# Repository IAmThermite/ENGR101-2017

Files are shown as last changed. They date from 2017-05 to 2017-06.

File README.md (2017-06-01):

# Team *High Ground* AVC


## Team Members
* Tom - Head of Software - tom.buurmans@gmail.com
* Isaac - Hardware - isaachamiltonj@gmail.com
* Xavier - Software - Xavier.Broadhead@gmail.com
* Raven - Head of Hardware - Ravengotztier@icloud.com
* Luke - Admin - luke.honiss@gmail.com

## Information
* [Google Docs Link](https://docs.google.com/document/d/1r9uR-22ZHVupD0Ts2tCpkkdqB7kD9Vjael_ExiJzlJU/edit?usp=sharing)
    * This will be a general place for team members to put code snippets or paste pictures of progress and more general items that don't belong directly on this document.
* We are using a Facebook Group chat to communicate
<table>
   <th colspan="3">First robot design</th>
   <tr>
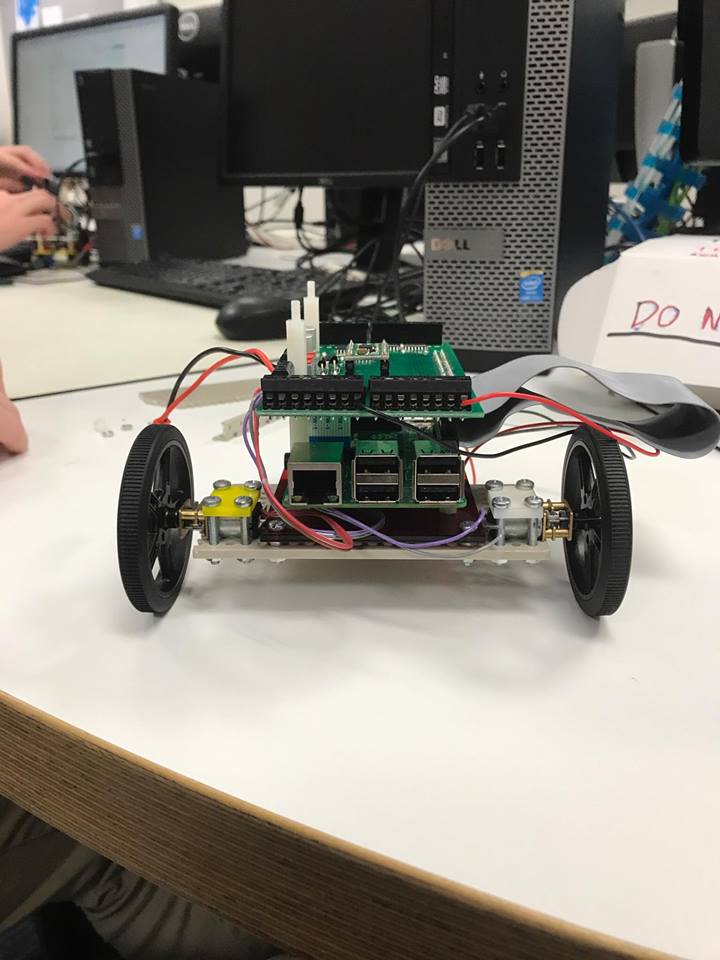
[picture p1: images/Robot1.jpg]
Robot 1
      <td></td>
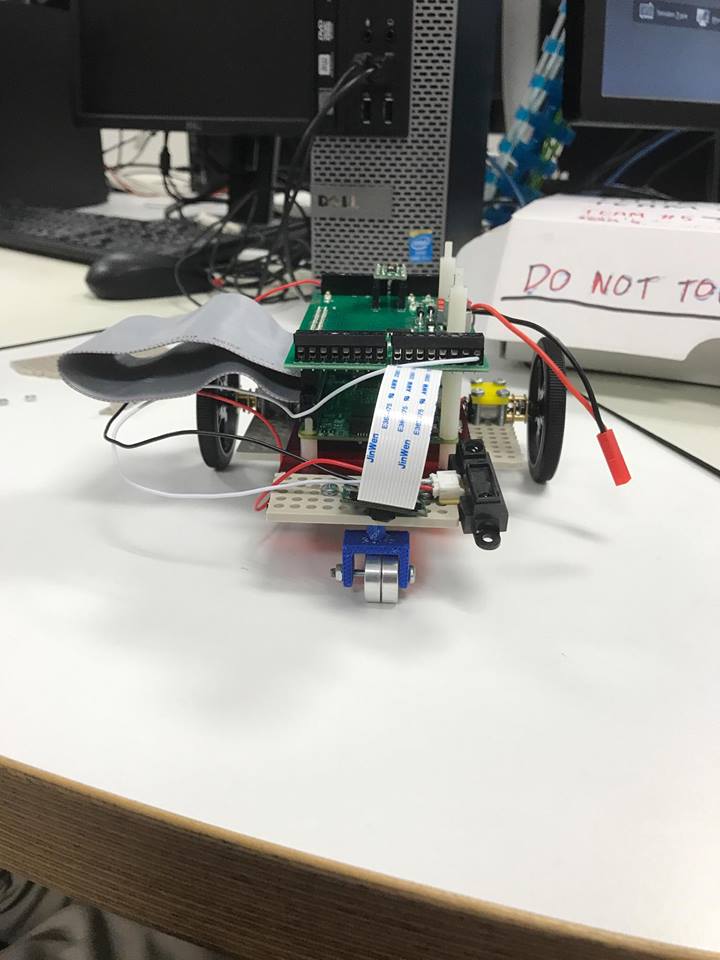
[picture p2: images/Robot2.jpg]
Robot 2
      <td></td>
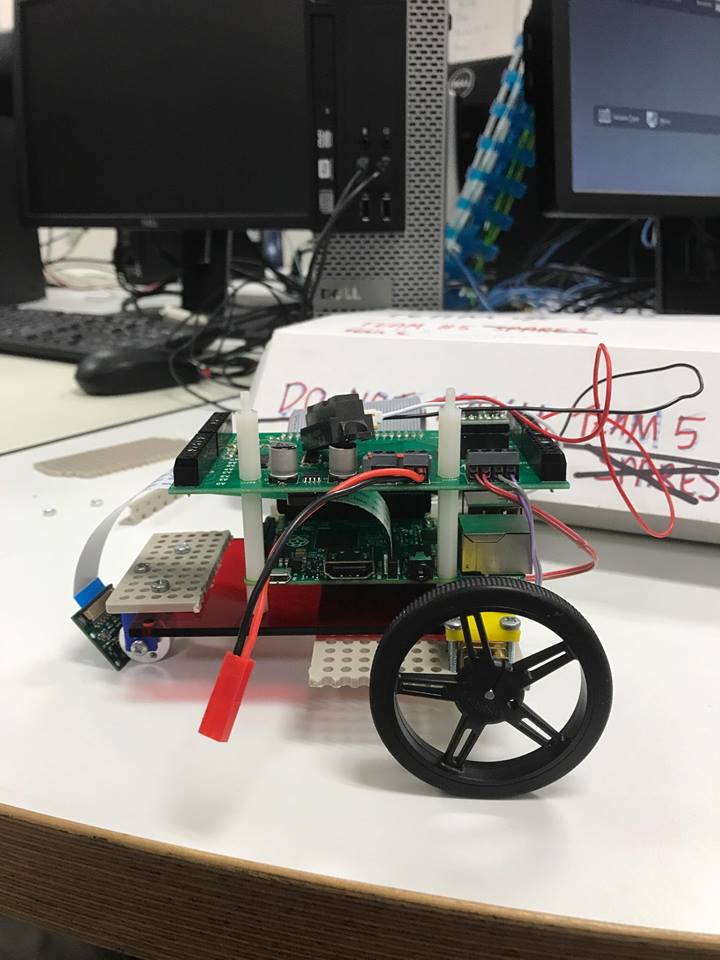
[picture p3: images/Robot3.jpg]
Robot 3
      <td></td>
   </tr>
   <th colspan="3">Final robot designs</th>
   <tr>
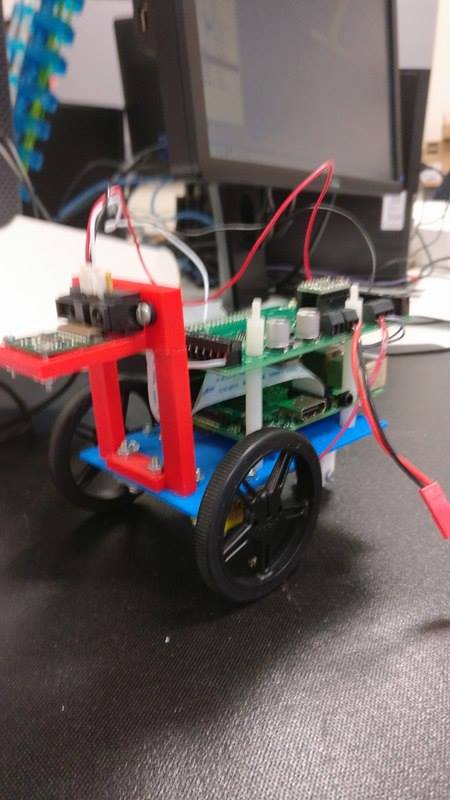
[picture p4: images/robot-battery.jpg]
Complete robot without battery
      <td></td>
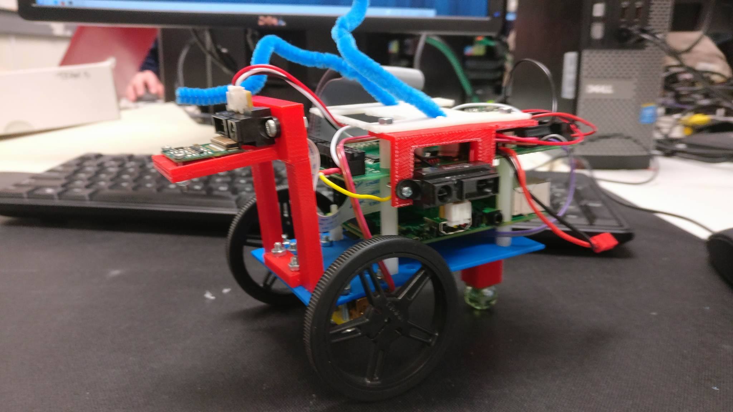
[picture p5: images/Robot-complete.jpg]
Complete robot
      <td colspan="2"></td>
   </tr>
</table>

## Coding Guidelines
* 4 spaces in place of a tab (can be configured through Geany)
* Comments before each method and wherever possible
* Using underscores (`_`) in variable and method names (e.g. `my_method()`, `my_var`)
* Constants will be in 'UPPER_CASE'
* Opening curly brace will be on the same line as the method/statement declaration (i.e.)
```c
int main() {
    if(true) {
        print("true");
    } else {
        print("false");
    }
    
    return 0;
}
```

## Project Plan
| Week | Dates | Objective | Items Due | Conflicts | Tasks |
| ---- | ----- | --- | --- | --- | ----- |
| 1 | 1-5/5 | Robot Moving<br/>Chassis Design | AVC Plan | | [W1 Checklist](https://github.com/LuciusDev/ENGR101-2017/blob/master/README.md#week-1) |
| 2 | 8-12/5 | Chassis Complete<br />Base Code | | | [W2 Checklist](https://github.com/LuciusDev/ENGR101-2017/blob/master/README.md#week-2) |
| 3    | 15-19/5 | Quad1&2 Complete | COMP102 Test | | [W3 Checklist](https://github.com/LuciusDev/ENGR101-2017/blob/master/README.md#week-3) |
| 4    | 22-26/5 |Quad3 Complete | AVC Progress | ENGR121 Test | [W4 Checklist](https://github.com/LuciusDev/ENGR101-2017/blob/master/README.md#week-4) |
| 5    | 29/5-2/6 | Quad4 Complete | **AVC Challenge** | | [W5 Checklist](https://github.com/LuciusDev/ENGR101-2017/blob/master/README.md#week-5) |

## Weekly Checklists
### Week 1
- [x] [ALL] Sort out team roles
- [x] [ALL] Team name
- [x] [ALL] Sign team agreement
- [x] [ALL] Create team schedule
- [x] [Luke] Setup team GitHub Repository
- [ ] [Raven] Ideal robot mockup

#### Review
We are still to complete the mockup for the robot and complete the chassis for the robot. We had problems with attaching the motors to the GPIO pins, however the code we wrote worked fine (examples/forward.cpp).

### Week 2
- [x] [Raven] Ideal robot mockup
- [ ] [Raven] Mounting for camera, IR, and motors
- [x] [Raven] Wheel guiding system
- [ ] [Raven] Finish chassis
- [x] [SOFTWARE] Camera code
- [ ] [SOFTWARE] Robot can follow line
- [ ] [SOFTWARE] WiFi gate works
- [ ] [SOFTWARE] Test code

#### Review
We have done a lot of work this week. We managed to make a basic robot chasis with the parts that we could get. We have not yet finished the chasis but are not too far off it. Our hardware team will be completing the chasis at home. The software is pretty much complete for quadrant 1 which is very helpful. All of the team except Luke will be comming back on friday to complete the chasis and tidy stuff up.

### Week 3
- [x] [HARDWARE] Complete CAD files
- [x] [HARDWARE] 3d print parts
- [x] [HARDWARE] Finish chassis
- [x] [SOFTWARE] Test code
- [x] [HARDWARE] Mount camera, IR, and motors
- [ ] [SOFTWARE] Robot can follow line
- [x] [SOFTWARE] WiFi gate works
- [x] [SOFTWARE] Implement derivitive signal
- [ ] [SOFTWARE] Refine constants
- [x] [HARDWARE] Refine Robot Design
- [ ] [ALL] Quad 1&2 complete

#### Review
Unfortunately we were unable to get to use the 3D printers on Tuesday. We completed most of the CAD files there and made a few adjustments later in our own time. On Thursday we managed to get all our important parts printed and mounted. If we get the oppurtunity on Friday we may come back and try to do some testing. On Friday we managed to print out the final part of the chassis and test the gate opening. The gate now fully opens so it is working as expected.

### Week 4
- [ ] [ALL] Quad 1&2&3 complete
- [x] [SOFTWARE] Test code
- [x] [SOFTWARE] Robot can follow line
- [x] [SOFTWARE] WiFi gate works
- [x] [SOFTWARE] Refine constants

#### Review
We made a huge amount of progress on the robot this week. On Tuesday we began testing and got the robot to follow the line. The constants are all working as expected. The robot can go through Quad 1 and 2 all the time and Quad 3 is very nealy complete. We had to change the rear wheel to a marble as the robot was not turning correctly in Quad 3. Code for Quad 4 needs to be written however the chassis is complete.

### Week 5
- [ ] [ALL] Quad Quad 1&2&3&4 complete
- [x] [ALL] Finishing touches
- [x] AVC CHALLENGE COMPLETED!

#### Review
A large section of the code and sections of the chassis were modified before the final run. Unfortunately the robot was not complete and it only managed 50% of the maze. This was probably due to a few things. One of the motors had begun to spin slower than the other. This caused it to veer of slightly and not turn correctly. Due to the position of the camera it appeared that it was picking up a little bit of white dust on the track which caused it to veer off completely in Quad 2. Also some parts of the software had not been debuged correctly so changes had to be made quickly and were not completely tested. The chassis got 3 points taken off it due to the back wheel being not very sturdy (it became loose before the maze) and a few other little things

### Weekly Progress Checklist
* [ALL] Each member/team completed their valid tasks
* [ALL] New goal for each member/team
* [Luke] Next week finalised
* [Luke] Review completed
* [Luke] Meetings finalised
* [Luke] Updated GitHub
    * [ALL] Code/pictures etc. committed
* [ALL] Extra tasks discussed

[pic]: https://m.popkey.co/fe3716/AlpAp_s-200x150.gif "We have the high ground"

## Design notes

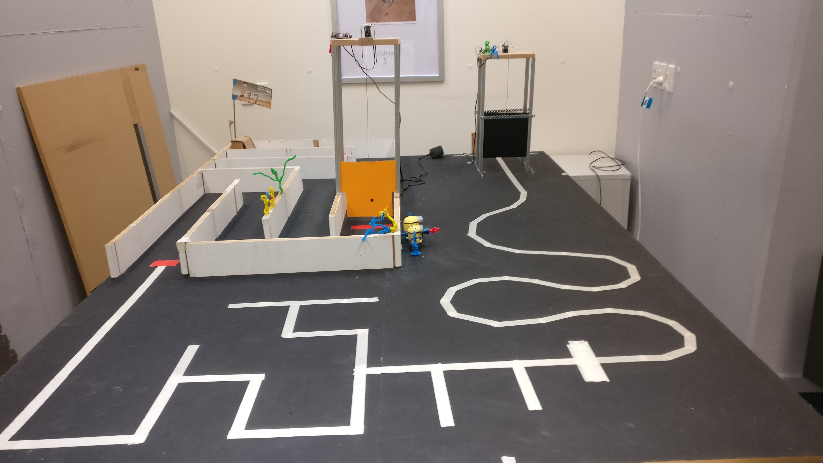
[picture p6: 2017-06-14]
images/Maze.jpg

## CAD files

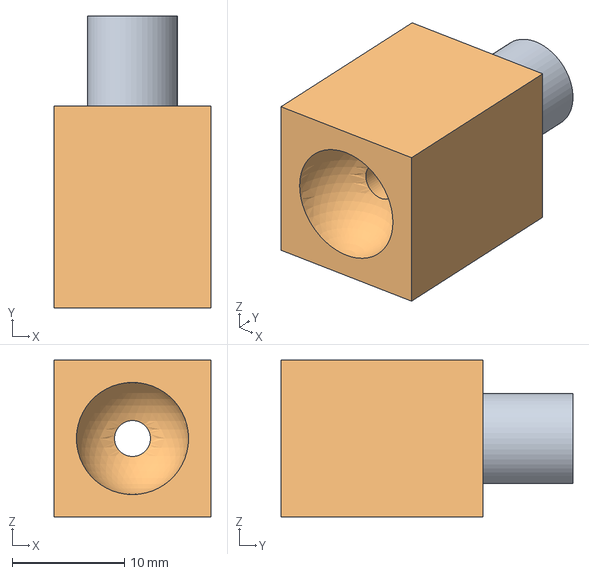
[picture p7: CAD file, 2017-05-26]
cad/wheel_mount_new.fcstd
14.0 x 26.0 x 14.0 mm

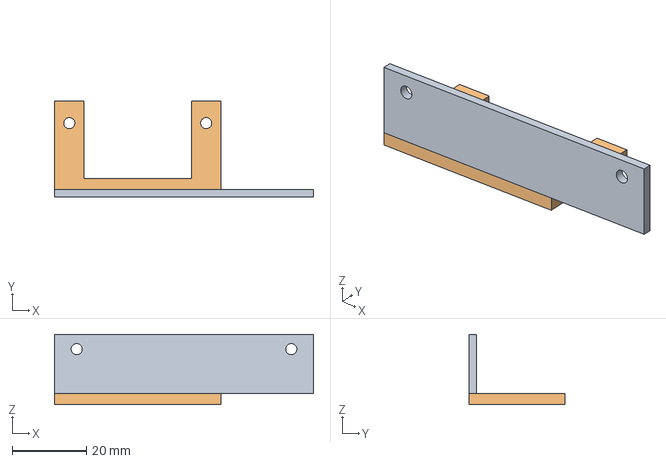
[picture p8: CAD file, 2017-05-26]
cad/ir_bracket.fcstd
70.0 x 26.0 x 19.0 mm

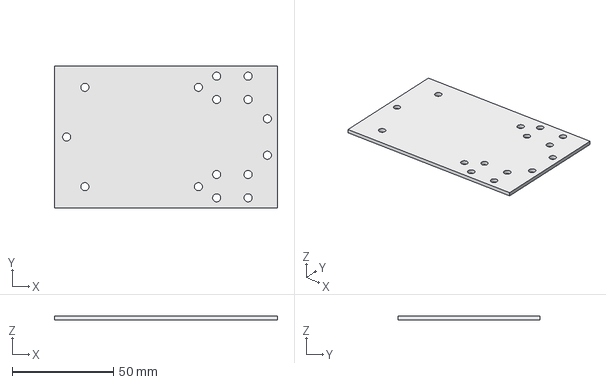
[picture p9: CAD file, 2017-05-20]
cad/chassis base.fcstd
110.0 x 70.0 x 2.00 mm

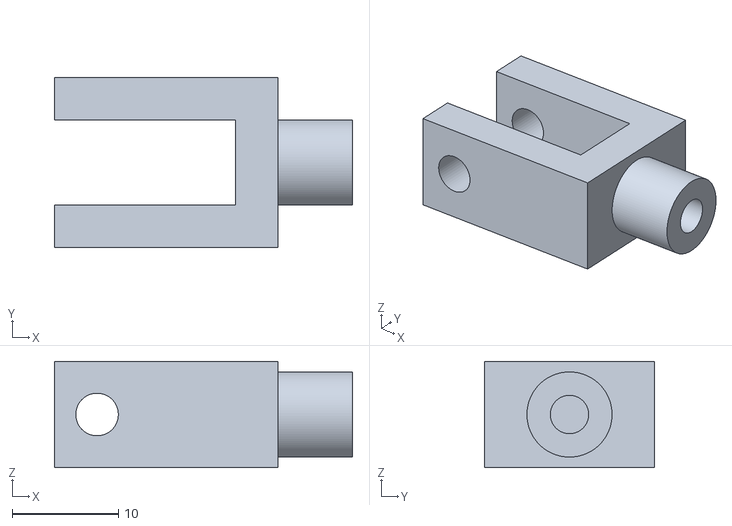
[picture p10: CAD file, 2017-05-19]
cad/wheel.stl
28.0 x 16.0 x 10.0

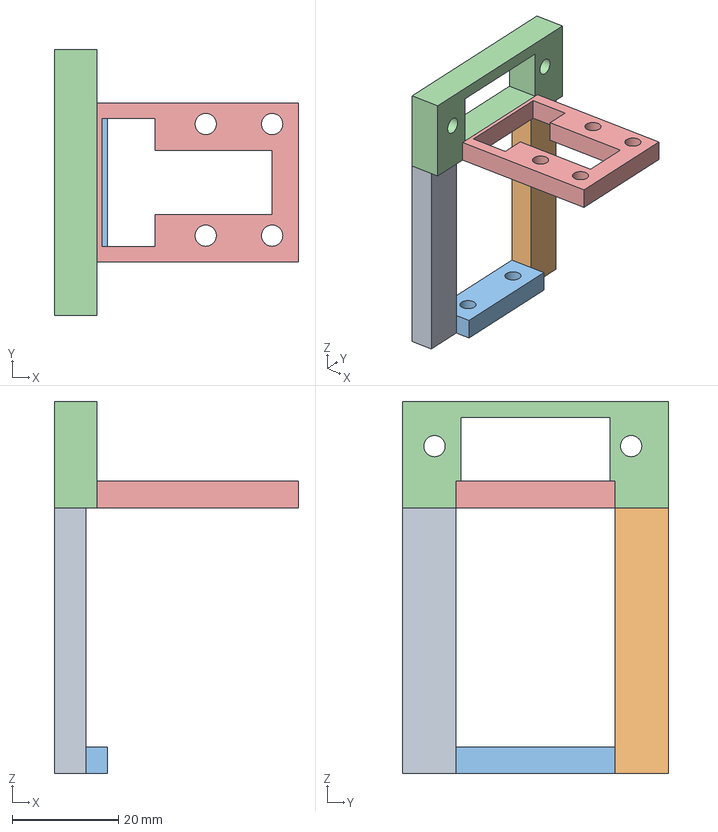
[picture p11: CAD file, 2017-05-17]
cad/cammount.FCStd
46.0 x 50.0 x 70.0 mm
right stand
left stand

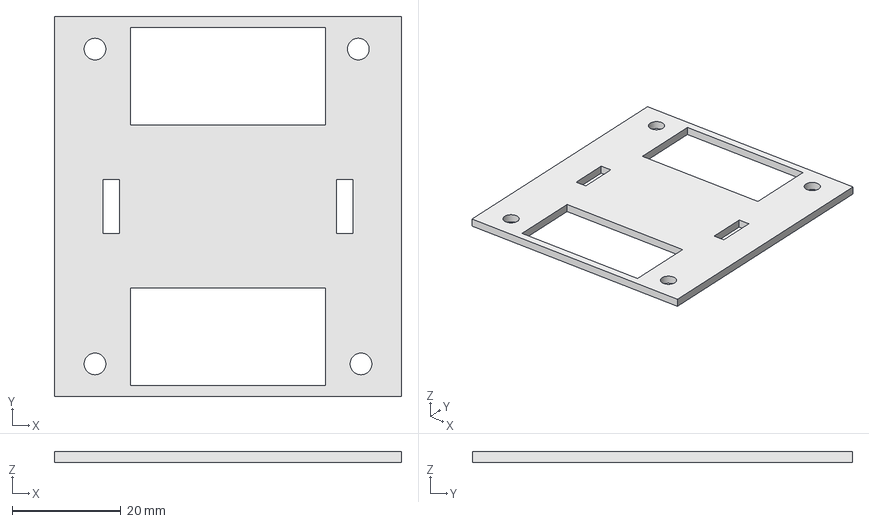
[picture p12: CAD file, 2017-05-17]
cad/battery.fcstd
64.0 x 70.0 x 2.00 mm

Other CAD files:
cad/chassis.stl
cad/wheel bracket.fcstd
cad/battery.stl
cad/cammount.stl
cad/ir_bracket.stl
cad/wheel_mount_new.stl

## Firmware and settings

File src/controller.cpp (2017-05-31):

//10.140.30.163 is our ip of our pi
//left motor = 1, right motor = 2
//front IR = 0, left IR = 1
//g++ -o controller controller.cpp -I../ -le101

#include <stdio.h>
#include <time.h>
#include <unistd.h>
#include "E101.h"

//constants
const int THRESHOLD = 80; //white value
const int RED_THRESHOLD = 120; //red value
const int GATE_DIST = 300; //distance to gate
const int WALL_DIST = 420; //front ir to wall close
const int WALL_DIST_2 = 200; //front ir to wall farther
const int WALL_DIST_3 = 500; //left ir to wall, should be as close to this value as possible

const double SC_1 = 0.12; //error scale
const double SC_2 = 0.03; //derivitive scale

const double SC_IR = 0.05; //error scale

int quadrant = 1; //stores the number of the current quadrant


//MISC METHODS
/**
 * Trys to open the gate
 */
void open_gate() {
	char pw[] = "Please High Ground";
    char ip[] = "130.195.6.196";
    char mts[7];
    int port = 1024;

    connect_to_server(ip, port);
	send_to_server(pw); //send Please to server
	
	char message[24]; //message from server
   	receive_from_server(message); //this may be buggy!
    
    for(int i = 0; i < 6; i++) {
        mts[i] = message[i];
    }
    
    mts[6] = 0; //final digit is 0
    printf(mts);
    send_to_server(mts);
}

/**
 * returns the number of white pixels on the row
 * takes the channel and row as inputs
 */
int get_num_pixels(int row, int channel) {
    int num = 0;
    char pix[320];
    
    take_picture();

    if(channel == 3) { //white
        for(int i = 0; i < 320; i++) {
            pix[i] = get_pixel(row, i, channel);
            if(pix[i] > THRESHOLD) {
                num++;
            }
        }
    } else { //not white so must be red
        for(int i = 0; i < 320; i++) {
            pix[i] = get_pixel(row, i, channel);
            if(pix[i] > RED_THRESHOLD) {
                num++;
            }
        }
    }

    return num;
}

/**
 * returns the number of white pixels on the column
 * takes the channel and column as inputs
 */
int get_num_pixels_col(int col, int channel) {
    int num = 0;
    
    take_picture();
    
    for(int i = 0; i < 240; i++) {
        if(get_pixel(i, col, channel) > THRESHOLD) {
            num++;
        }
    }
    
    printf("NUM: %d\n", num);
    return num;
}

/**
 * returns the number of error value of a line
 * takes the row as an input
 */
int get_error(int row) {
    int err = 0;
    int nwp = get_num_pixels(row, 3);
    char pix[320];
    
    take_picture();
    
    for(int i = 0; i < 320; i++) {
        pix[i] = get_pixel(120, i, 3);
        if(pix[i] > THRESHOLD) {
            err = err + (i-160);
        }
    }
    
    if(nwp <= 0) {
        return 0;
    } else {
        return (err/nwp);
    }
    
}


//IR METHODS
/**
 * returns the ir reading for the IR sensor at the specified pin
 */
int get_distance_to_wall(int pin) {
    int total = 0;
    
    for(int i = 0; i < 5; i++) {
	    total = total + read_analog(pin); //ir is at A0
    }
	return (int)(total/5);
}


//MOVE METHODS
/**
 * moves the robot depending on the distance
 * from the line
 */
void move(int err, int delta_err) {
	int speed_left;
	int speed_right;

	speed_left = 35 - (int)((double)err*SC_1) + (int)((double)delta_err*SC_2);
	speed_right = 35 + (int)((double)err*SC_1) - (int)((double)delta_err*SC_2);

    //ensure that the speed of the motors does not exceed 250/-250
    if(speed_left > 250) {
        speed_left = 250;
    } else if(speed_left < -250) {
        speed_left = -250;
    }

    if(speed_right > 250) {
        speed_right = 250;
    } else if(speed_right < -250) {
        speed_right = -250;
    }
    printf("err:%d derr:%d\n", (int)(err*SC_1), (int)(delta_err*SC_2));
    printf("L:%d R:%d\n", speed_left, speed_right);

	set_motor(1, speed_right);
	set_motor(2, speed_left * -1); //right so must move in -ve direction

    sleep1(0, 30000); //30ms
}

/**
 * Move method for the IR sensor
 */
void move_ir(int err) {
    
    int speed_left;
    int speed_right;
    
    speed_left = 50 - (int)((double)err*SC_IR);
    speed_right = 50 + (int)((double)err*SC_IR);
    
    //ensure that the speed of the motors does not exceed 250/-250
    if(speed_left > 250) {
        speed_left = 250;
    } else if(speed_left < -250) {
        speed_left = -250;
    }

    if(speed_right > 250) {
        speed_right = 250;
    } else if(speed_right < -250) {
        speed_right = -250;
    }

    printf("l: %d, r: %d\n", speed_left, speed_right);
    
	set_motor(1, speed_right);
	set_motor(2, speed_left * -1); //right so must move in -ve direction

    sleep1(0, 30000); //30ms
}

/**
 * Moves the robot back a bit when we cant find the line
 */
void back() {
	//Error correcting by moving backwards if the whiteline cannot be found
    printf("##BACK##\n");
	set_motor(1, -40);
	set_motor(2, 40);
	sleep1(0, 70000); //70ms
}

/** 
 * Turns the robot left
 */
void turn_left_line() {
    printf("##LEFT##\n");
    
    while(get_num_pixels(40, 3) < 10) { //while it cant find any pixels at front
	set_motor(1, -40);
	set_motor(2, -40);
        sleep1(0, 10000);
    }
}

/** 
 * Turns the robot right on the line
 */
void turn_right_line() {
    printf("##RIGHT##\n");
    
    while(get_num_pixels(40, 3) < 10) { //while it cant find any pixels at front
        set_motor(1, 40);
	    set_motor(2, 40);
        sleep1(0, 10000);
    }
}

/**
 * Turn left for the IR
 */
void turn_left_ir() { //turn left for 2.5 sec
    printf("##IR LEFT##\n");
    while(get_distance_to_wall(0) > WALL_DIST_2){
        set_motor(1, -40);
        set_motor(2, -40);
        sleep1(0, 50000);
    }

}

/**
 * Turn right for the IR
 */
void turn_right_ir() { //turn left for 2.5 sec
    printf("##IR RIGHT##\n");
    while(get_distance_to_wall(0) > WALL_DIST_2){
        set_motor(1, 40);
        set_motor(2, 40);
        sleep1(0, 50000);
    }
}


//LINE READING METHODS
/**
 * Checks to see if the line is completely white
 * in which case we are in quad3
 */
bool is_full_white_line() {
    if(get_num_pixels(120, 3) > 270) {
        return true;
    } else {
        return false;
    }
}

/**
 * Checks to see if the line is completely red
 */
bool is_full_red_line() {
    if(get_num_pixels(120, 0) > 270) {
        return true;
    } else {
        return false;
    }
}

/**
 * will use the camera to try and find the line
 * will call the move method
 */
void find_line() {
    int err1 = get_error(120); //error signal for first row
    int err2 = get_error(20); //error signal for second row
	
    int nwp = get_num_pixels(120, 3); //Number of white pixels
	int delta_err = err1 - err2;
    
	if (nwp != 0) { //if no white pixels
		err1 = (int)(err1);
		move(err1, delta_err);
	
    } else {
		back(); //no white pixels found, we have lost the line
	}
}

/**
 * find line for the maze (quadrant 3)
 */
void find_line_maze() {
    //trigger a particular method
    int line = 0; //front 0, right 1, left 2

	while(true) {
        //front
        if (get_num_pixels(120, 3)>20){ //enough white for front line
            line = 0;
            break;
        }
        
        //left        
        if (get_num_pixels_col(20, 3)>20){ //enough white for left line
            line = 1;
            break;
        }

        //right
        if (get_num_pixels_col(300, 3)>20){
            line = 2;
            break;
        }
        
        back(); //obvoiusly broken
    }
	
    if (line == 0){
		printf("FRONT\n");
		find_line();
	} else if (line == 1){
		turn_left_line();
		find_line();
	} else if (line == 2){
		turn_right_line();
		find_line();
	}
}

/**
 * find the wall, for the IRWALL_DIST_3
 */
void find_wall() {
    int err_front = get_distance_to_wall(0);
    int err_side = get_distance_to_wall(1);
    int err = err_side - WALL_DIST_3;
    
    if(err_front < WALL_DIST) { //not too close at front
        if(err_side > WALL_DIST_3) { // too close to left so shuffle a bit
            move_ir(err * -1); //turn right
            
        } else { //too close right so shuffle a bit
            move_ir(err); //turn left
        }
        
    } else { //too close at front so we need to turn 90
        if(err_side > WALL_DIST_3) { //too close left
            turn_right_ir();
        } else {
            turn_left_ir();
        }
    }
}


//
//MAIN QUADRANT METHODS
//
/**
 * The quadrant 1 code
 */
void quadrant1() {
    while(true) {
        if(get_distance_to_wall(0) > GATE_DIST) {
            open_gate(); //try to open the gate
            quadrant = 2;
            break;
            
        } else {
            find_line();
        }
    }
}

/**
 * The quadrant 2 code 
 */
void quadrant2() {
     while(true) {
         if(!is_full_white_line()) {
             find_line();
        } else {
            quadrant = 3;
            break;
        }
    }
}

/**
 * The quadrant 3 code
 */
void quadrant3() {
    while(true) {
        if(!is_full_red_line()) {
            find_line_maze();
        } else {
            quadrant = 4;
            break;
        }
    }
}

/**
 * The quadrant 4 code
 */
void quadrant4() {
    while(true) {
        find_wall();
    }
}


//MAIN
/**
 * Main method
 */
int main(){	
    init();
    sleep1(0, 1000); //sleep a bit
    
    while(true) {
        if(quadrant == 1) {
            printf("	## STARTING QUAD1\n");
            quadrant1();
        } else if(quadrant == 2) {
            printf("	## STARTING QUAD2\n");
            quadrant2();	
        } else if(quadrant == 3) {
            printf("    ## STARTING QUAD3\n");
            quadrant3();   
        } else if(quadrant == 4) {
            printf("	## STARTING QUAD4\n");
            quadrant4();
        }
    }

    return 0;
}

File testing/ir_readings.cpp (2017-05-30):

#include <stdio.h>
#include <time.h>
#include "E101.h"

int main() {
    init();
    sleep1(0, 1000);
    int total_ave;
    int total = 0;
    int readings = 10;
    int adc_reading;

    printf("FRONT\n");

    for(int i = 0; i < readings; i++) {
        for(int j = 0; j < readings; j++) {
            adc_reading = read_analog(0);
            
            sleep1(0, 100000);
            total = total+adc_reading;
        }
        printf("Ave of %d readings: %d\n", readings, total/readings);
        total = 0;
    }

    printf("    Ave of %d average readings: %d\n", readings, total_ave/readings);
    
   total_ave = 0;

    printf("LEFT");

    for(int i = 0; i < readings; i++) {
        for(int j = 0; j < readings; j++) {
            adc_reading = read_analog(1);
            
            sleep1(0, 100000);
            total = total+adc_reading;
        }
        printf("Ave of %d readings: %d\n", readings, total/readings);
        total = 0; 
}
    
    printf("    Ave of %d average readings: %d\n", readings, total_ave/readings);

    return 0;
}

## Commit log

2017-04-12 Update and rename main.cpp to number-printer.cpp
    Changed printf() from character to number and renamed file
2017-05-09 Create camera
2017-05-09 testing camera code
2017-05-10 Added check motor
    The left motor is on pin 1
2017-05-16 chassis design
    Design for the base of the robot that the other parts will be added onto
    [chassis.stl]
2017-05-16 Added design files for the chassis
    [chassis base.fcstd]
2017-05-16 Added camera/ir component
    [cammount.FCStd, frame.stl]
2017-05-16 Delete frame.stl
    Holes were off by a little bit
    [frame.stl]
2017-05-16 Add files via upload
    Made a battery mount and fixed the camera/ir mount
    [battery.fcstd, battery.stl, cammount.FCStd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]
2017-05-17 Fixed some cad files
    [battery.fcstd, battery.stl, cammount.FCStd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]
2017-05-17 Made a wheel mount
    [wheel bracket.fcstd, wheel.stl]
2017-05-19 Updated cad files
    [wheel bracket.fcstd, wheel.stl]
2017-05-19 Fixed some compile issues
    [controller.cpp]
2017-05-20 Edited CAD files
    [chassis base.fcstd, chassis.stl]
2017-05-25 Finally fixed PID and other stuff
    [controller.cpp]
2017-05-25 New back guide mount
    [wheel_mount_new.fcstd, wheel_mount_new.stl]
2017-05-26 Added IR mount files
    [ir_bracket.fcstd, ir_bracket.stl]
2017-05-29 Fixed a random error
    [controller.cpp]
